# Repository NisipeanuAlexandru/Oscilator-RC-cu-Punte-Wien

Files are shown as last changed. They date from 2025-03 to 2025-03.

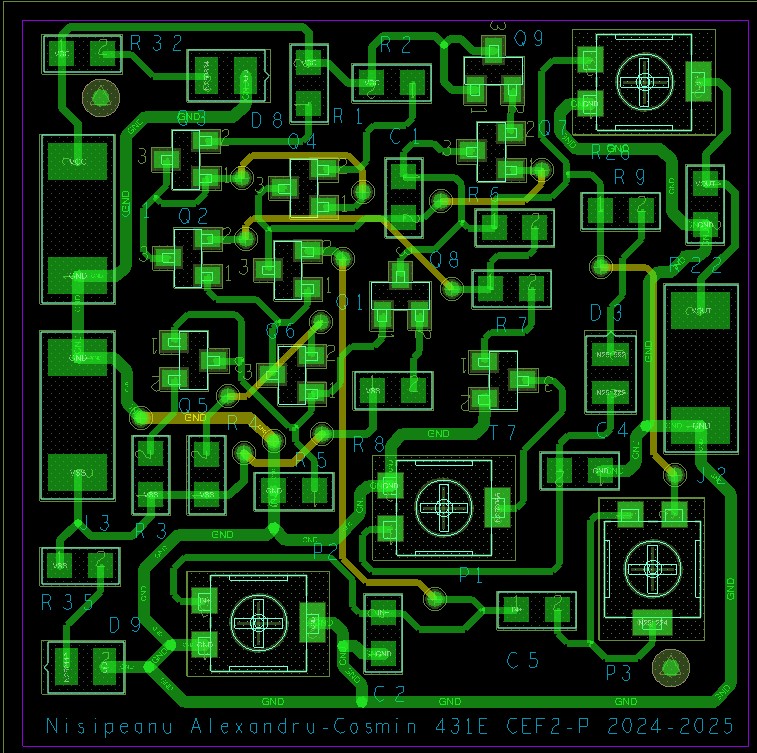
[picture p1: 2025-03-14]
Layout/layout.jpg

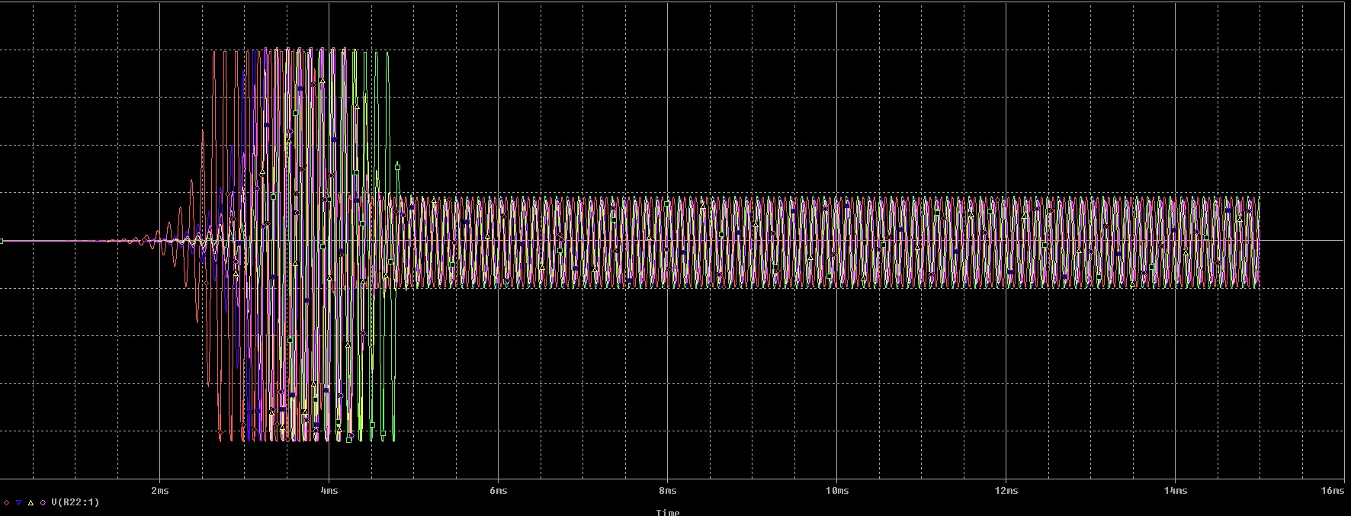
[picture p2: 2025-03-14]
Simulations/transient_-20_120.jpg

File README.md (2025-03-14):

# README - Oscilator RC cu Punte Wien

## Descriere Generală
Oscilatorul RC cu punte Wien este un circuit utilizat pentru generarea de semnale sinusoidale de frecvență reglabilă. Acesta este alcătuit dintr-o rețea RC în configurație Wien și un amplificator cu control automat al amplitudinii (TEC-J). Circuitul este destinat utilizării în diverse aplicații electronice unde este necesară o sursă de semnal sinusoidal stabilă și ajustabilă.

## Caracteristici Tehnice
- **Frecvență de oscilație reglabilă**: 7,5 - 45 kHz
- **Sarcină la ieșire**: 15 kΩ
- **Control automat al amplitudinii**: realizat cu TEC-J
- **Amplitudinea oscilației la ieșire**: 20/1,5*15 V
- **Domeniul temperaturilor de funcționare**: 0 - 70°C
- **Semnalizare a tensiunilor de alimentare**: LED

## Funcționalitate
Oscilatorul Wien utilizează o rețea de rezistențe și condensatori pentru a stabili frecvența de oscilație. Acesta include:
1. **Rețeaua Wien (RC)** - determină frecvența semnalului de ieșire.
2. **Amplificator operațional sau tranzistor** - menține oscilațiile în circuit.
3. **Control automat al amplitudinii** - stabilizează amplitudinea oscilatorului printr-un element de feedback, cum ar fi un TEC-J (Thermally Controlled Junction).
4. **Sistem de semnalizare LED** - indică prezența tensiunii de alimentare.

## Tehnologii de Realizare
Oscilatorul poate fi realizat utilizând două metode:
- **SMT & PCB**: Tehnologie avansată pentru performanță ridicată și fiabilitate (100 puncte max.)
  - Placă PCB FR4, dublu strat, dimensiuni 40x40mm
  - Componente SMD de tip 0805
  - Tranzistoare bipolare și TEC-MOS în capsule SMD (SOT23, D-PAK)
  - Layer special pentru marcaje și identificare
- **THT & Perfo-board**: Tehnologie mai simplă, accesibilă pentru prototipare rapidă (70 puncte max.)
  - Componente montate pe perfo-board
  - Necesită plan de plantare detaliat

## Simulare și Testare
- Se utilizează software-ul OrCAD pentru simulare și proiectare PCB.
- Se verifică funcționarea în intervalul de temperaturi specificat.
- Se validează fișierele Gerber și Excellon pentru fabricație PCB.

## Concluzie
Oscilatorul RC cu punte Wien este un circuit stabil și eficient pentru generarea semnalelor sinusoidale. Alegerea între SMT & PCB sau THT & Perfo-board depinde de cerințele aplicației și de nivelul de complexitate dorit în realizarea practică.

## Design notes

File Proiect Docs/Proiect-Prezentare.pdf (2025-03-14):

## UNIVERSITATEA NAȚIONALĂ DE ȘTIINȚĂ ȘI TEHNOLOGIE POLITEHNICA DIN BUCUREȘTI

Facultatea de Electronica, Telecomunicatii si Tehnologia Informatiei

Proiect CEF2 Tema:

## Oscilator RC cu reactive Wien

### Nisipeanu Alexandru-Cosmin

Grupa : 431E

Bucuresti 2024

Date initiale de proiectare: N=15
Să se proiecteze și realizeze un oscilator RC cu punte Wien având următoarele caracteristici:
- Frecventa de oscilaţie reglabilă în intervalul 7,5 45 [KHz];
- Sarcina la ieşire 15 [k ];
- Control automat al amplitudinii de oscilaţie realizat cu TEC-J;
- Amplitudinea oscilaţiei la ieşire 0,88 [V];
- Domeniul temperaturilor de funcționare: 0⁰

-70⁰C (verificabil prin testare în temperatură);

Semnalizarea prezenței tensiunilor de alimentare cu diodă de tip LED.

Schema bloc a circuitului

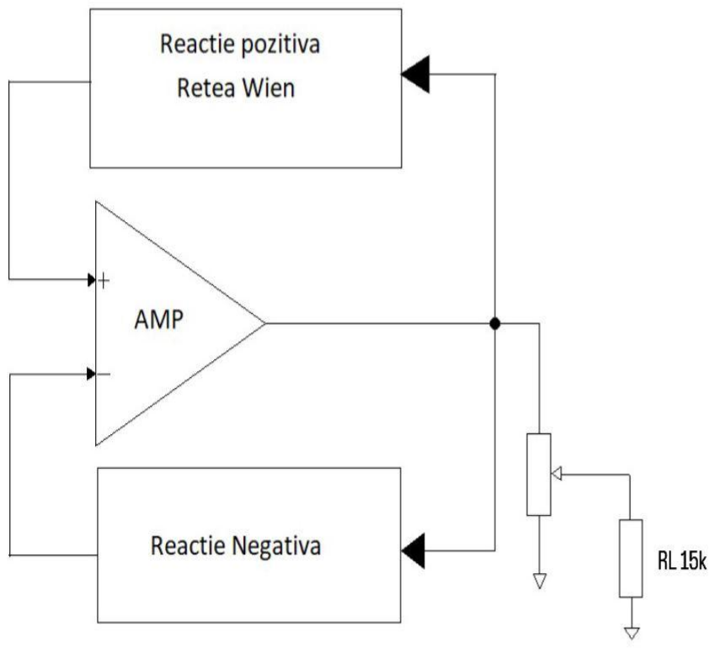
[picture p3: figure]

Oscilatorul RC:

Oscilatorul RC se utilizeaza in generatoare de audiofrecventa. Au reactive pozitiva selective, avand cuadripolul de reactive construit din rezistente si condensatoare.

Configuratia oscilatorului, in majoritatea situatiilor, corespunde unui amplificator cu reactive pozitiva cu transmisia pe bucla unitara egala cu A*β(ωn)=1.

Relația de mai sus reprezintă condiția de oscilație sau condiția Barkhausen, unde A este câștigul amplificatorului, iar β este funcția de transfer a rețelei de reacție pozitivă (RRP).

În general atât amplitudinea cât și factorul de transfer sunt mărimi complexe, astfel incât relaţia Barkhausen între numere complexe este echivalentă cu două condiţii reale:

Condiția de modul sau de amplitudine: | β (jω) | * | A (jω) | = 1;

Condiția de argument sau fază: arg(β) + arg(A) = φβ + φA = 0;

Schema electrica:

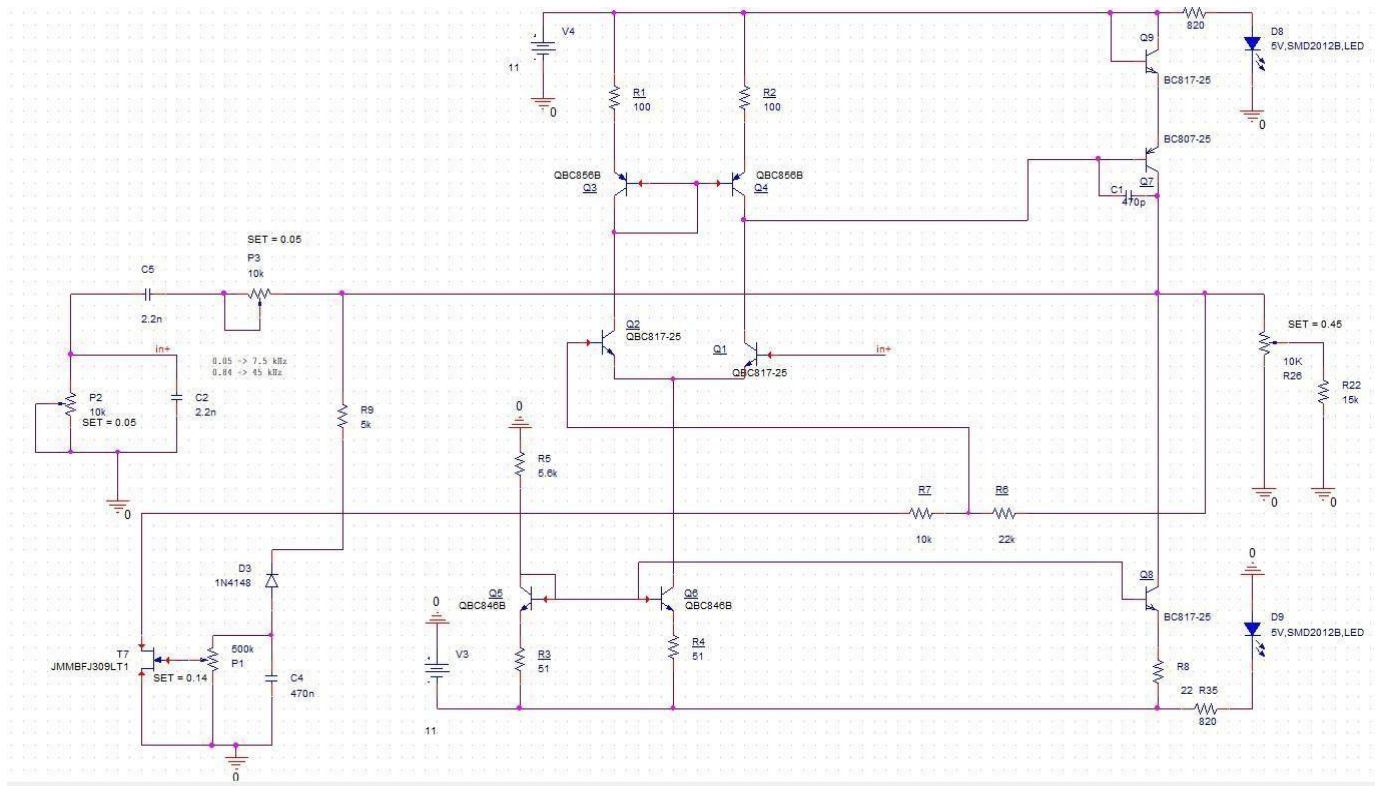
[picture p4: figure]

Etajul diferential de intrare este alcatuit din tranzistorii Q1 si Q2, acesta fiind un etaj de amplificare in tensiune si curent . Q3 si Q4 alcatuiesc sarcina activa a etajului diferential, egaland curentii prin cele doua ramuri ale acestuia. Q3 este referinta de oglinda /tranzistor dioda si perimte iesirea din etajul de amplificare asimetric, deci nu se injumatateste amplificarea etajului.

Q7 = al doilea etaj de amplificare de tip emitor comun in clasa A. Amplifica in tensiune, amplificarea sa in curent fiind ~ 1.

Etajele de amplificare pentru a functiona au nevoie de un curent constant.
Sursa de current Q6 polarizeaza etajul diferential.
Sursa de curent Q8 polarizeaza etajul de amplificare emitor comun (Q7) Curentul de referinta pentru polarizarea etajelor este generat pe ramura cu rezistorul R5 si R3 + tranzistorul in conexiune dioda Q5. Curentul generat astfel este preluat prin tranzistorul Q5 (referinta oglinzii) si distribuit la celelalte ramuri (catre etajul diferential – Q6, catre etajul emitor comun Q8)
Rezistoarele R3, R4, R8 permit obtinerea unor curenti diferiti prin fiecare ramura in functie de raportul rezistentelor acestora. De asemenea se numesc rezistente de degenerare care au rol in imperecherea tensiunilor VBE din oglinda de curent si de asemenea au rol in imbunatatirea variatiilor cu temperatura.

Reactia pozitiva:

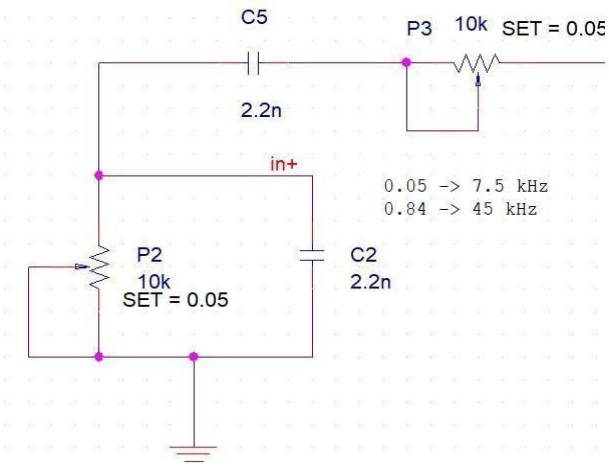
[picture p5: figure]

Componentele P3, P2, C5, C2 realizeaza un filtru trece banda care are frecventa de trecere egala cu frecventa de oscilatie.
Fosc = 1/2πRC, in conditia in care C = C5 = C2 si R = P3 = P2
Frecventa o reglam din potentiometrele de mai sus (P2,3)
C2=C5=2.2n;
P2=P3∈[0; 10]kOhm;

Reactia negative:

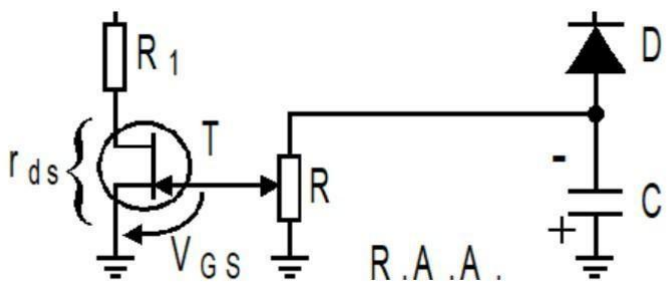
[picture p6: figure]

E constituita din rezistente R7, R6 si rezistenta canalului tranz JFET – T7. Se observă că acest circuit înlocuieşte una din rezistenţele circuitului de reacţie negativă al amplificatorului cu ajutorul căruia este realizat oscilatorul.
Dioda D realizează funcţia de detecţie (redresare de frecvenţă ridicată) a semnalului de la ieşirea oscilatorului lăsând să treacă doar alternanţa negativă, în care dioda este polarizată direct. Această tensiune pulsatorie încarcă condensatorul C la o tensiune negativă, condensatorul realizând filtrarea acestor pulsuri. Pentru ca tensiunea negativă de la bornele condensatorului să fie aproximativ constantă trebuie îndeplinită condiţia fosc RC >>1. Cu ajutorul potenţiometrului R este polarizat tranzistorul T care, fiind cu canal n, are o tensiune de comandă VGS < 0. Rezistenţa rds a tranzistorului T, ce face parte din reţeaua de reacţie negativă a amplificatorului, este dependentă de tensiunea de comandă
VGS. Cu cât valoarea absolută a tensiunii de comandă |VGS | este mai mare, cu atât canalul
conductor dintre drenă şi sursă este mai îngust şi deci rds este mai mare.
Această dependenţă a rezistenţei este însă comandată de amplitudinea tensiunii de oscilaţie prin intermediul circuitului descris anterior.
Deoarece expresia amplificării este AV=1+R6/R7>3 , variatia rezistentei rds determina:
-o scădere a amplificării dacă amplitudinea oscilaţiei are tendinţa de creştere; -o creştere a amplificării dacă amplitudinea oscilaţiei are tendinţa de scădere.

Calcule- punctul static de functionare

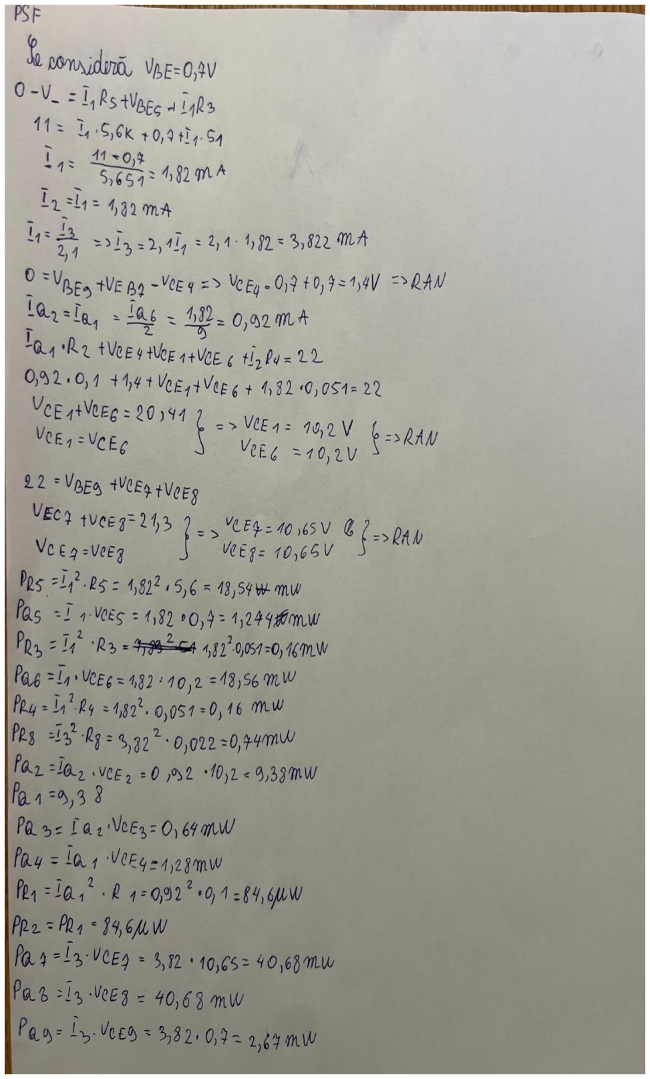
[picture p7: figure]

Punctul static de functionare- Simulat

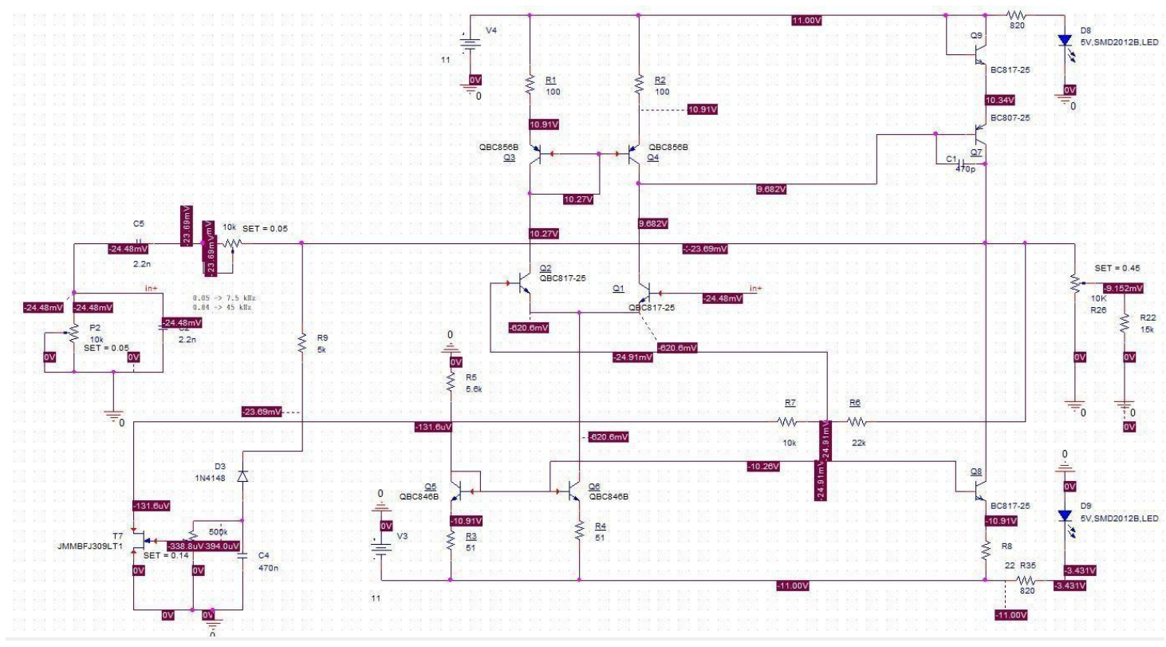
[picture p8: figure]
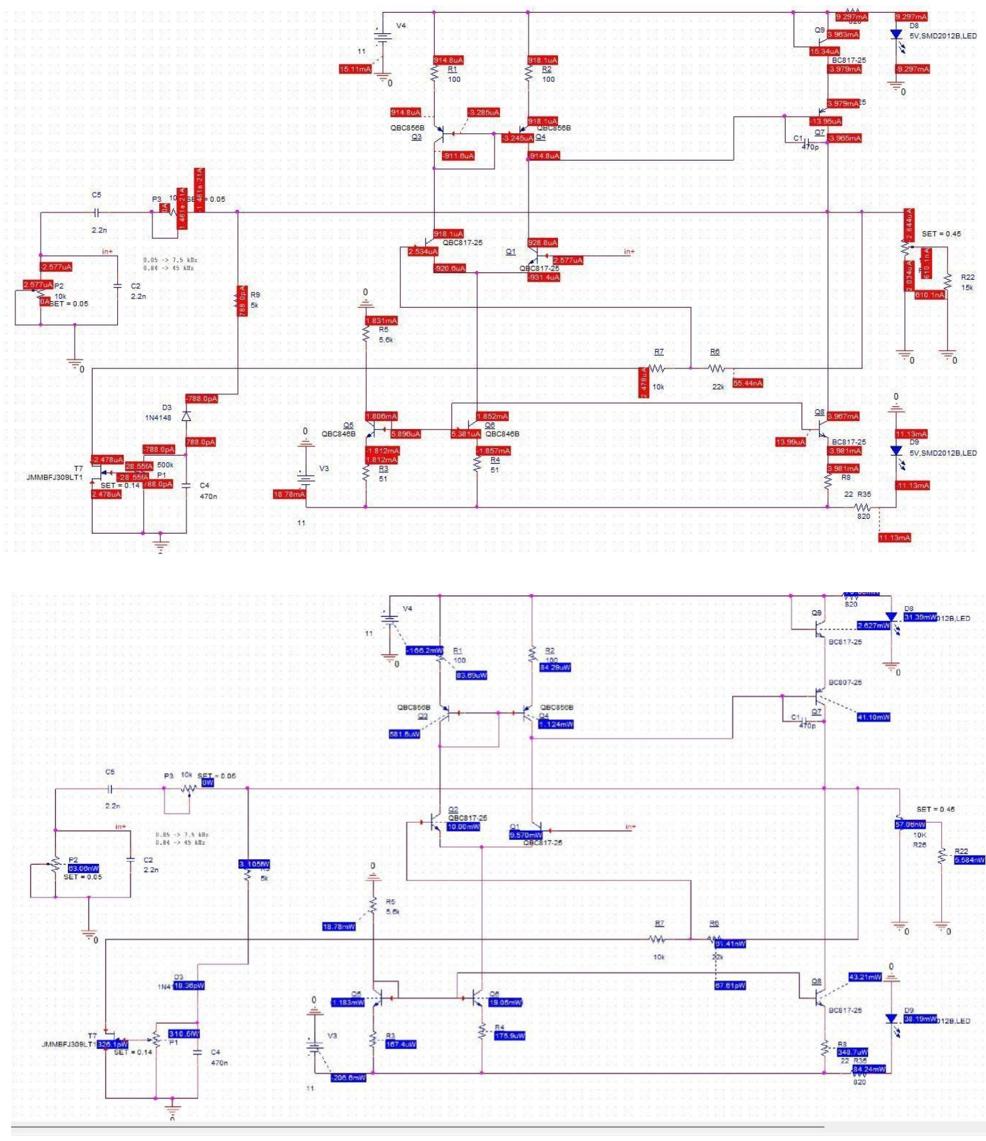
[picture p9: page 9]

Analiza in timp, transient

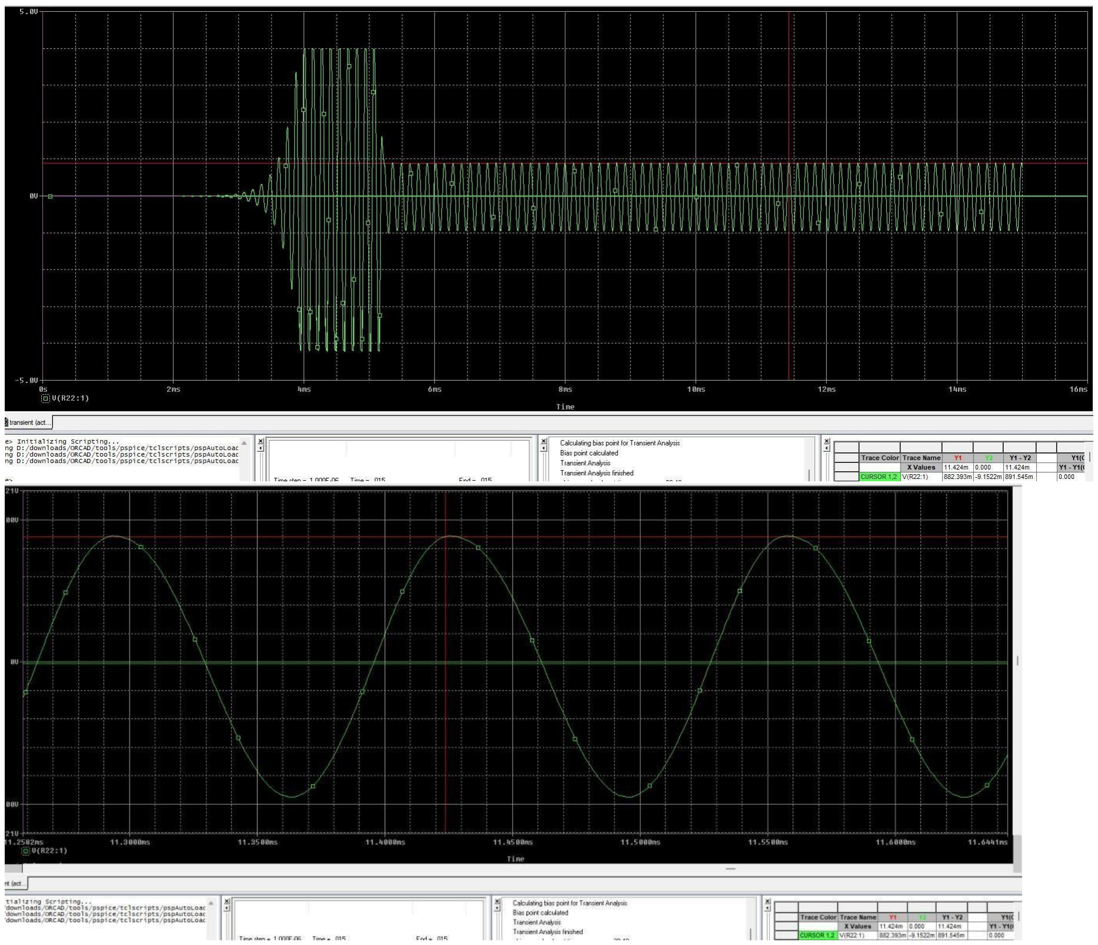
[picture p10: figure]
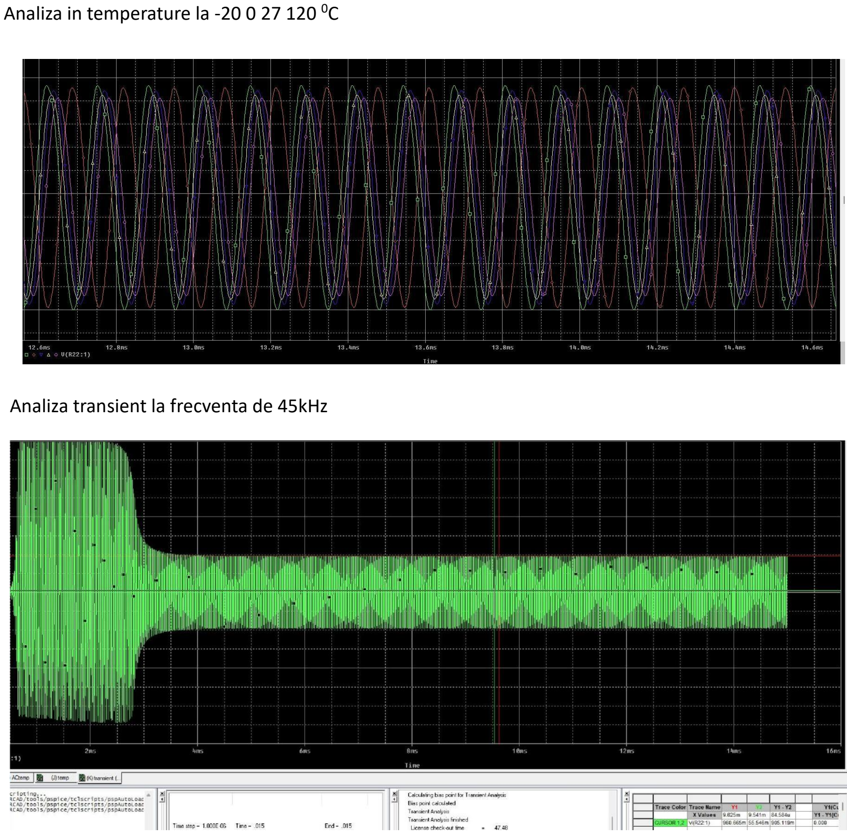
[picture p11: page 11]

Analiza in temperature la -20 0 27 120 ⁰C

Analiza transient la frecventa de 45kHz

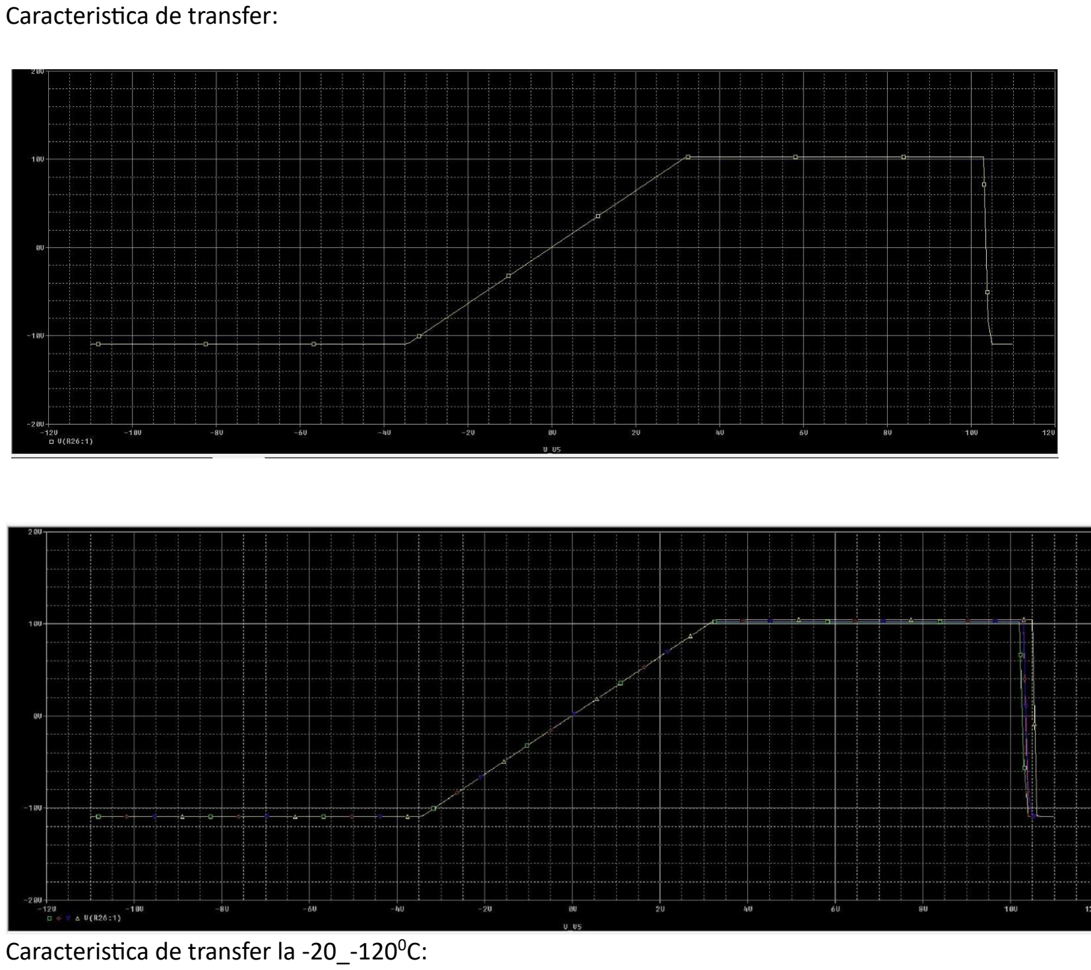
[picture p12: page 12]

Caracteristica de transfer:

Caracteristica de transfer la -20_-120⁰C:

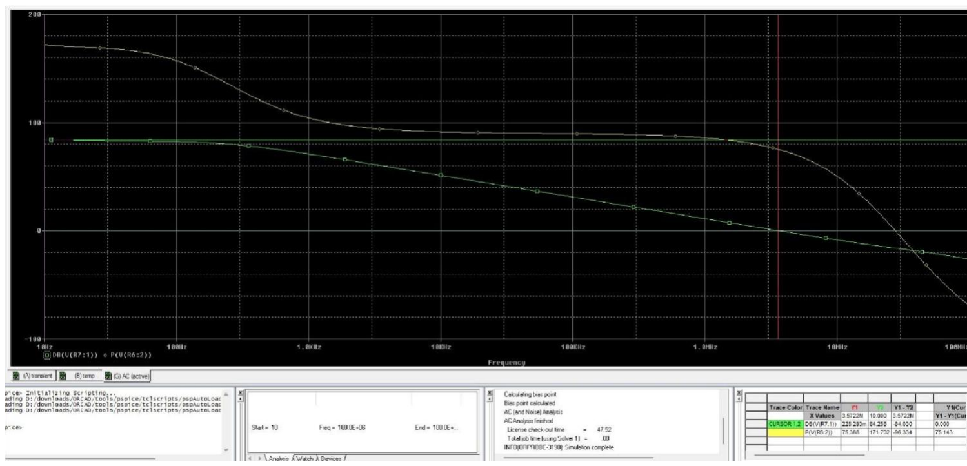
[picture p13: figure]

Analiza AC stabilitate:

Analiza AC staabilitate la -20_120⁰C:

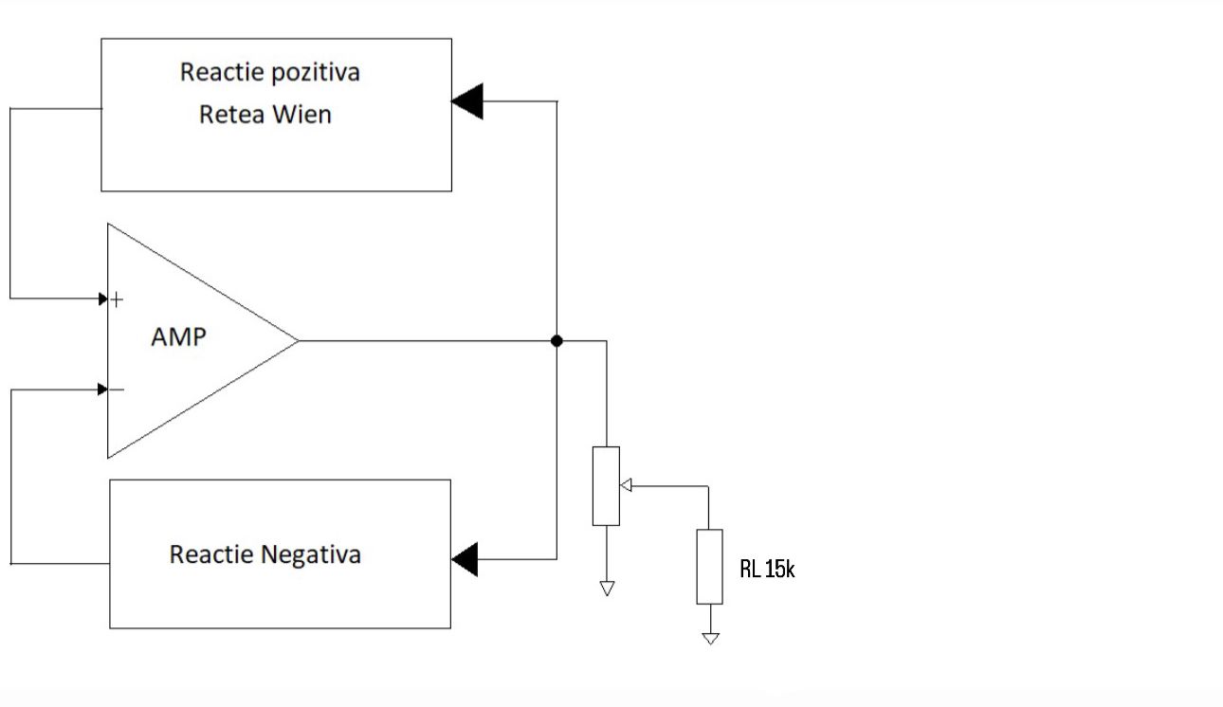
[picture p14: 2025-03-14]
Schema_bloc.jpg

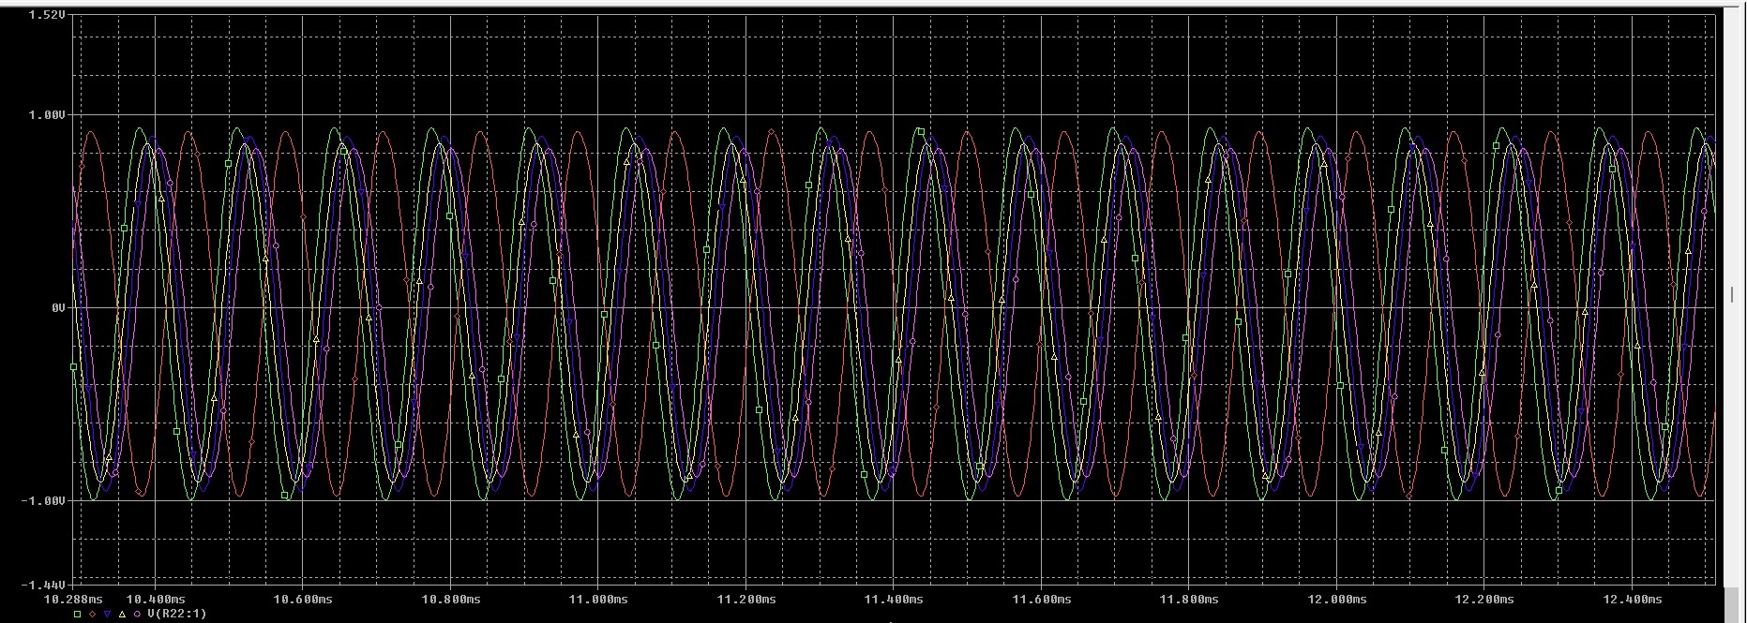
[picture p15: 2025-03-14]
Simulations/transient(zoom)_-20_120.jpg

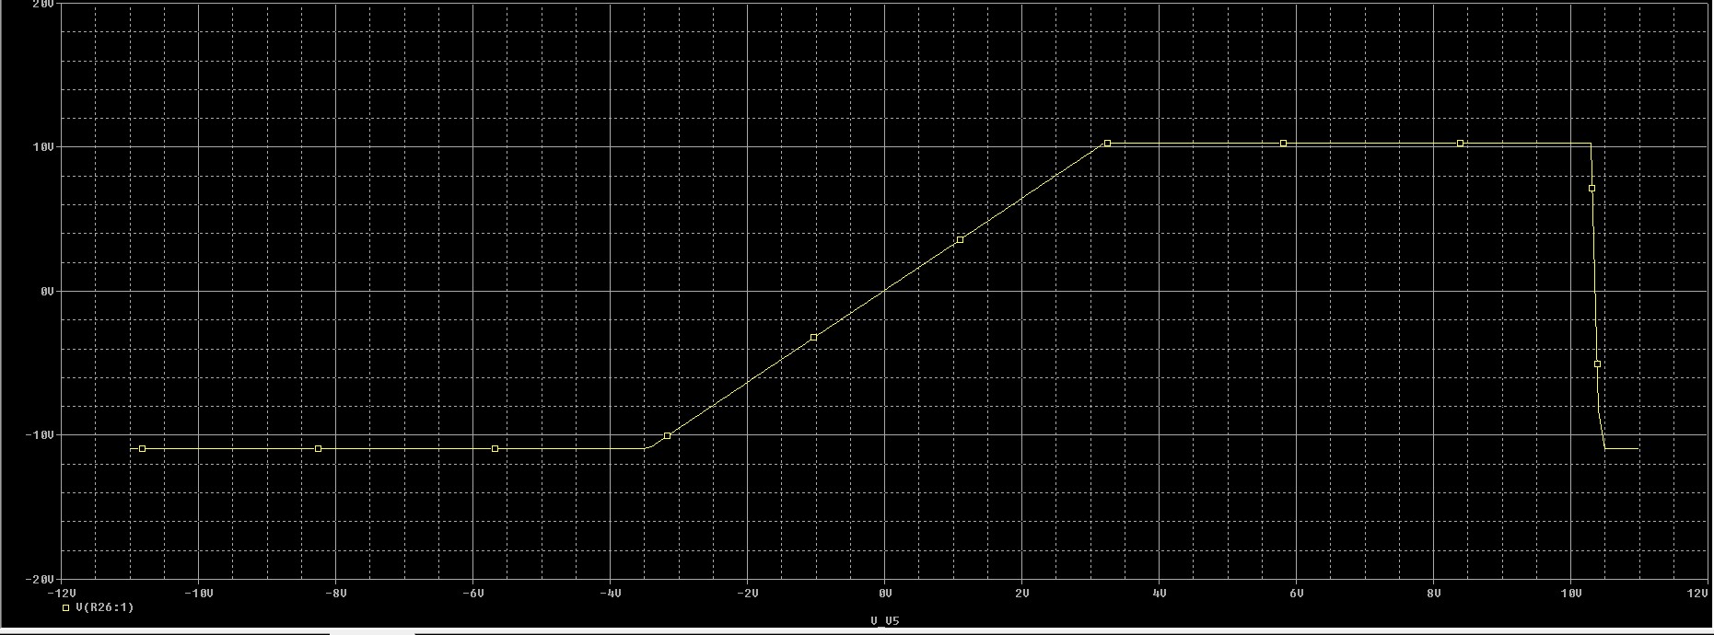
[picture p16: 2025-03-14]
Simulations/Caracteristica_de_transfer.jpg

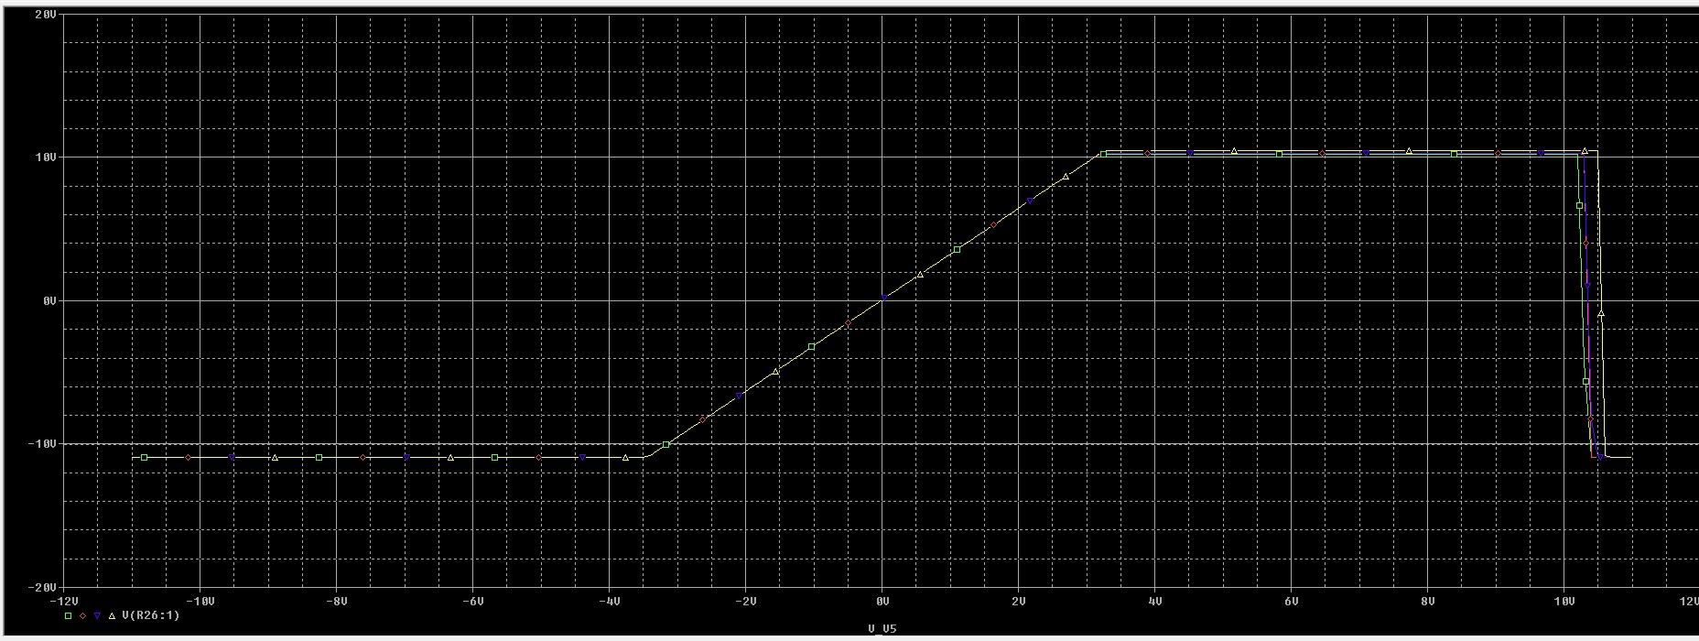
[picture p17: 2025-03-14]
Simulations/Caracteristica_de_transfer_-20_120.jpg

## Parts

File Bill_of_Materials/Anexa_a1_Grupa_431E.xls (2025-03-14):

Anexa a1 - Grupa 431E - Tema 1- Oscilator RC cu retea Wien
Nr. Crt. | Nume | Catalog | Cod distrib | Nume prod | Prod | Clasă | Qty fix | Qty final | Qty min | Descriere | Distribuitor | Pret (fara TVA) referinta/buc. TME România | Pret total pe reper (fara TVA) - propus
1 | 0 ohm | (LINK) (http://www.tme.eu/ro/details/smd1206-0r/rezistente-smd-1206/royal-ohm/1206s4j0000t5e/) | 1206S4J0000T5E | 1206S4J0000T5E | SR PASSIVES | rezistor | 0 |  | 0 | Rezistor: thick film; SMD; 1206; 0Ω; 0,25W; ±5%; -55÷125°C | TME România | 0.03841 | 0
2 | 0.47 | (LINK) (http://www.tme.eu/ro/details/smd0805-0r47/rezistente-smd-0805/royal-ohm/0805s8j047kt5e/) | SMD0805-0R47 | 0805S8J047KT5E | ROYAL OHM | rezistor | 20 |  | 0 | Rezistor SMD, chip, 0805, 0.47Ω, ±5%, 0.125W | TME România | 0.01454 | 0.2908
3 | 1 | (LINK) (https://www.tme.eu/ro/details/smd0805-1r/rezistente-smd-0805/royal-ohm/0805s8j010jt5e/) | SMD0805-1R-5% | 0805S8J010JT5E | ROYAL OHM | rezistor | 20 |  | 0 | Rezistor SMD, chip, 0805, 1Ω, ±5%, 0.125W | TME România | 0.01723 | 0.3446
4 | 4.7 | (LINK) (https://www.tme.eu/ro/details/smd0805-4r7/rezistente-smd-0805/royal-ohm/0805s8j047jt5e/) | SMD0805-4R7-5% | 0805S8J047JT5E | ROYAL OHM | rezistor | 10 |  | 0 | Rezistor SMD, chip, 0805, 4.7Ω, ±5%, 0.125W | TME România | 0.01723 | 0.1723
5 | 10 | (LINK) (https://www.tme.eu/ro/details/smd0805-10r/rezistente-smd-0805/royal-ohm/0805s8j0100t5e/) | SMD0805-10R-5% | 0805S8J0100T5E | ROYAL OHM | rezistor | 10 |  | 0 | Rezistor SMD, chip, 0805, 10Ω, ±5%, 0.125W | TME România | 0.01723 | 0.1723
6 | 22 | (LINK) (https://www.tme.eu/ro/details/smd0805-22r-1%25/rezistente-smd-0805/royal-ohm/0805s8f220jt5e/) | SMD0805-22R-1% | 0805S8F220JT5E | ROYAL OHM | rezistor | 20 |  | 1 | Rezistor SMD, chip, 0805, 22Ω, ±1%, 0.125W | TME România | 0.02127 | 0.4254
7 | 33 | (LINK) (https://www.tme.eu/ro/details/smd0805-33r/rezistente-smd-0805/royal-ohm/0805s8j0330t5e/) | SMD0805-33R-5% | 0805S8J0330T5E | ROYAL OHM | rezistor | 20 |  | 0 | Rezistor SMD, chip, 0805, 33Ω, ±5%, 0.125W | TME România | 0.01723 | 0.3446
8 | 51 | (LINK) (http://www.tme.eu/ro/details/rc0805jr-0751r/rezistente-smd-0805/yageo/rc0805jr-0751rl/) | SMD0805-51R-5% | 0805S8J0510T5E | ROYAL OHM | rezistor | 40 |  | 2 | Rezistor SMD, chip, 0805, 51Ω, ±5%, 0.125W | TME România | 0.0261 | 1.044
9 | 68 | (LINK) (http://www.tme.eu/ro/details/smd0805-68r-1%25/rezistente-smd-0805/royal-ohm/0805s8f680jt5e/) | SMD0805-68R-1% | 0805S8F680JT5E | ROYAL OHM | rezistor | 10 |  | 0 | Rezistor SMD, chip, 0805, 68Ω, ±1%, 0.125W | TME România | 0.04662 | 0.4662
10 | 82 | (LINK) (https://www.tme.eu/ro/details/wf08p-82r-5%25/rezistente-smd-0805/walsin/wf08p820jtl/) | SMD0805-82R-5% | WF08P820JTL | WALSIN | rezistor | 20 |  | 0 | Rezistor SMD, chip, 0805, 82Ω, ±5%, 0.125W | TME România | 0.0172 | 0.344
11 | 100 | (LINK) (https://www.tme.eu/ro/details/smd0805-100r/rezistente-smd-0805/royal-ohm/0805s8j0101t5e/) | SMD0805-100R-5% | 0805S8J0101T5E | ROYAL OHM | rezistor | 60 |  | 2 | Rezistor SMD, chip, 0805, 100Ω, ±5%, 0.125W | TME România | 0.01723 | 1.0338
12 | 150 | (LINK) (https://www.tme.eu/ro/details/smd0805-150r/rezistente-smd-0805/royal-ohm/0805s8j0151t5e/) | SMD0805-150R-5% | 0805S8F1500T5E | ROYAL OHM | rezistor | 30 |  | 0 | Rezistor SMD, chip, 0805, 150Ω, ±5%, 0.125W | TME România | 0.01723 | 0.5169
13 | 220 | (LINK) (http://www.tme.eu/ro/details/smd0805-220r-1%25/rezistente-smd-0805/royal-ohm/0805s8f2200t5e/) | SMD0805-220R-5% | 0805S8J0221T5E | ROYAL OHM | rezistor | 30 |  | 0 | Rezistor SMD, chip, 0805, 220Ω, ±5%, 0.125W | TME România | 0.02127 | 0.6381
14 | 330 | (LINK) (https://www.tme.eu/ro/details/smd0805-330r/rezistente-smd-0805/royal-ohm/0805s8j0331t5e/) | SMD0805-330R-5% | 0805S8J0331T5E | ROYAL OHM | rezistor | 30 |  | 0 | Rezistor SMD, chip, 0805, 330Ω, ±5%, 0.125W | TME România | 0.01723 | 0.5169
15 | 470 | (LINK) (https://www.tme.eu/ro/details/smd0805-470r/rezistente-smd-0805/royal-ohm/0805s8j0471t5e/) | SMD0805-470R-5% | 0805S8J0471T5E | ROYAL OHM | rezistor | 30 |  | 0 | Rezistor SMD, chip, 0805, 470Ω, ±5%, 0.125W | TME România | 0.01723 | 0.5169
16 | 510 | (LINK) (https://www.tme.eu/ro/details/smd0805-510r/rezistente-smd-0805/royal-ohm/0805s8j0511t5e/) | SMD0805-510R-5% | 0805S8J0511T5E | YAGEO | rezistor | 30 |  | 0 | Rezistor SMD, chip, 0805, 510Ω, ±5%, 0.125W | TME România | 0.01723 | 0.5169
17 | 680 | (LINK) (https://www.tme.eu/ro/details/smd0805-680r/rezistente-smd-0805/royal-ohm/0805s8j0681t5e/) | SMD0805-680R-5% | 0805S8J0681T5E | ROYAL OHM | rezistor | 30 |  | 0 | Rezistor SMD, chip, 0805, 680Ω, ±5%, 0.125W | TME România | 0.01723 | 0.5169
18 | 820 | (LINK) (https://www.tme.eu/ro/details/smd0805-820r/rezistente-smd-0805/royal-ohm/0805s8j0821t5e/) | SMD0805-820R-5% | 0805S8J0821T5E | ROYAL OHM | rezistor | 30 |  | 2 | Rezistor SMD, chip, 0805, 820Ω, ±5%, 0.125W | TME România | 0.01723 | 0.5169
19 | 910 | (LINK) (https://www.tme.eu/ro/details/rc0805jr-07910r/rezistente-smd-0805/yageo/rc0805jr-07910rl/) | SMD0805-910R-5% | RC0805JR-07910RL | YAGEO | rezistor | 40 |  | 0 | Rezistor SMD, chip, 0805, 910Ω, ±5%, 0.125W | TME România | 0.0261 | 1.044
20 | 1k | (LINK) (https://www.tme.eu/ro/details/smd0805-1k/rezistente-smd-0805/royal-ohm/0805s8j0102t5e/) | SMD0805-1K-5% | 0805S8J0102T5E | ROYAL OHM | rezistor | 100 |  | 0 | Rezistor SMD, chip, 0805, 1kΩ, ±5%, 0.125W | TME România | 0.01723 | 1.723
21 | 1.5k | (LINK) (https://www.tme.eu/ro/details/wf08p-1k5-5%25/rezistente-smd-0805/walsin/wf08p152jtl/) | SMD0805-1K5-5% | WF08P152JTL | WALSIN | rezistor | 40 |  | 0 | Rezistor SMD, chip, 0805, 1.5kΩ, ±5%, 0.125W | TME România | 0.0172 | 0.688
22 | 1.8k | (LINK) (https://www.tme.eu/ro/details/smd0805-1k8/rezistente-smd-0805/royal-ohm/0805s8j0182t5e/) | SMD0805-1K8-5% | 0805S8J0182T5E | ROYAL OHM | rezistor | 30 |  | 0 | Rezistor SMD, chip, 0805, 1.8kΩ, ±5%, 0.125W | TME România | 0.01723 | 0.5169
23 | 2k | (LINK) (https://www.tme.eu/ro/details/smd0805-2k/rezistente-smd-0805/royal-ohm/0805s8j0202t5e/) | SMD0805-2K-5% | 0805S8J0202T5E | ROYAL OHM | rezistor | 80 |  | 0 | Rezistor SMD, chip, 0805, 2kΩ, ±5%, 0.125W | TME România | 0.01723 | 1.3784
24 | 2.2k | (LINK) (https://www.tme.eu/ro/details/smd0805-2k2/rezistente-smd-0805/royal-ohm/0805s8j0222t5e/) | SMD0805-2K2-5% | 0805S8J0222T5E | ROYAL OHM | rezistor | 30 |  | 0 | Rezistor SMD, chip, 0805, 2.2kΩ, ±5%, 0.125W | TME România | 0.01723 | 0.5169
25 | 2.7k | (LINK) (https://www.tme.eu/ro/details/smd0805-2k7/rezistente-smd-0805/royal-ohm/0805s8j0272t5e/) | SMD0805-2K7-5% | 0805S8F2701T5E | ROYAL OHM | rezistor | 30 |  | 0 | Rezistor SMD, chip, 0805, 2.7kΩ, ±5%, 0.125W | TME România | 0.01723 | 0.5169
26 | 3.3k | (LINK) (https://www.tme.eu/ro/details/smd0805-3k3/rezistente-smd-0805/royal-ohm/0805s8j0332t5e/) | SMD0805-3K3-5% | 0805S8J0332T5E | ROYAL OHM | rezistor | 30 |  | 0 | Rezistor SMD, chip, 0805, 3.3kΩ, ±5%, 0.125W | TME România | 0.01723 | 0.5169
27 | 3.9k | (LINK) (https://www.tme.eu/ro/details/smd0805-3k9/rezistente-smd-0805/royal-ohm/0805s8j0392t5e/) | SMD0805-3K9-5% | 0805S8J0392T5E | ROYAL OHM | rezistor | 20 |  | 0 | Rezistor SMD, chip, 0805, 3.9kΩ, ±5%, 0.125W | TME România | 0.01723 | 0.3446
28 | 4.7k | (LINK) (https://www.tme.eu/ro/details/smd0805-4k7/rezistente-smd-0805/royal-ohm/0805s8j0472t5e/) | SMD0805-4K7-5% | 0805S8J0472T5E | ROYAL OHM | rezistor | 30 |  | 0 | Rezistor SMD, chip, 0805, 4.7kΩ, ±5%, 0.125W | TME România | 0.01723 | 0.5169
29 | 5.6k | (LINK) (https://www.tme.eu/ro/details/smd0805-5k6/rezistente-smd-0805/royal-ohm/0805s8j0562t5e/) | SMD0805-5K6-5% | 0805S8J0562T5E | ROYAL OHM | rezistor | 60 |  | 2 | Rezistor SMD, chip, 0805, 5.6kΩ, ±5%, 0.125W | TME România | 0.01723 | 1.0338
30 | 6.8k | (LINK) (https://www.tme.eu/ro/details/rc0805jr-076k8/rezistente-smd-0805/yageo/rc0805jr-076k8l/) | SMD0805-6K8-5% | RC0805JR-076K8L | YAGEO | rezistor | 20 |  | 0 | Rezistor SMD, chip, 0805, 6.8kΩ, ±5%, 0.125W | TME România | 0.0261 | 0.522
31 | 8.2k | (LINK) (https://www.tme.eu/ro/details/smd0805-8k2/rezistente-smd-0805/royal-ohm/0805s8j0822t5e/) | SMD0805-8K2-5% | 0805S8J0822T5E | ROYAL OHM | rezistor | 30 |  | 0 | Rezistor SMD, chip, 0805, 8.2kΩ, ±5%, 0.125W | TME România | 0.01723 | 0.5169
32 | 9.1k | (LINK) (https://www.tme.eu/ro/details/smd0805-9k1/rezistente-smd-0805/royal-ohm/0805s8j0912t5e/) | SMD0805-9K1-5% | 0805S8J0912T5E | ROYAL OHM | rezistor | 20 |  | 0 | Rezistor SMD, chip, 0805, 9.1kΩ, ±5%, 0.125W | TME România | 0.01723 | 0.3446
33 | 10k | (LINK) (https://www.tme.eu/ro/details/smd0805-10k/rezistente-smd-0805/royal-ohm/0805s8j0103t5e/) | SMD0805-10K-5% | 0805S8J0103T5E | ROYAL OHM | rezistor | 100 |  | 1 | Rezistor SMD, chip, 0805, 10kΩ, ±5%, 0.125W | TME România | 0.01723 | 1.723
34 | 15k | (LINK) (https://www.tme.eu/ro/details/smd0805-15k/rezistente-smd-0805/royal-ohm/0805s8j0153t5e/) | SMD0805-15K-5% | 0805S8J0153T5E | ROYAL OHM | rezistor | 30 |  | 1 | Rezistor SMD, chip, 0805, 15kΩ, ±5%, 0.125W | TME România | 0.01723 | 0.5169
35 | 22k | (LINK) (https://www.tme.eu/ro/details/smd0805-22k/rezistente-smd-0805/royal-ohm/0805s8j0223t5e/) | SMD0805-22K-5% | 0805S8J0223T5E | ROYAL OHM | rezistor | 30 |  | 1 | Rezistor SMD, chip, 0805, 22kΩ, ±5%, 0.125W | TME România | 0.01723 | 0.5169
36 | 47k | (LINK) (http://www.tme.eu/ro/details/smd0805-47k/rezistente-smd-0805/royal-ohm/0805s8j0473t5e/) | SMD0805-47K-5% | 0805S8J0473T5E | ROYAL OHM | rezistor | 40 |  | 0 | Rezistor: thick film; SMD; 0805; 47kΩ; 0,125W; ±5%; -55÷125°C | TME România | 0.01723 | 0.6892
37 | 68k | (LINK) (https://www.tme.eu/ro/details/smd0805-68k/rezistente-smd-0805/royal-ohm/0805s8j0683t5e/) | SMD0805-68K-5% | 0805S8J0683T5E | ROYAL OHM | rezistor | 20 |  | 0 | Rezistor SMD, chip, 0805, 68kΩ, ±5%, 0.125W | TME România | 0.01723 | 0.3446
38 | 100k | (LINK) (https://www.tme.eu/ro/details/smd0805-100k/rezistente-smd-0805/royal-ohm/0805s8j0104t5e/) | SMD0805-100K-5% | 0805S8J0104T5E | ROYAL OHM | rezistor | 100 |  | 0 | Rezistor SMD, chip, 0805, 100kΩ, ±5%, 0.125W | TME România | 0.01723 | 1.723
39 | 150k | (LINK) (http://www.tme.eu/ro/details/smd0805-150k/rezistente-smd-0805/royal-ohm/0805s8j0154t5e/) | SMD0805-150K-5% | 0805S8J0154T5E | ROYAL OHM | rezistor | 30 |  | 0 | Rezistor SMD, chip, 0805, 150kΩ, ±5%, 0.125W | TME România | 0.01723 | 0.5169
40 | 180k | (LINK) (http://www.tme.eu/ro/details/smd0805-180k/rezistente-smd-0805/royal-ohm/0805s8j0184t5e/) | SMD0805-180K-5% | 0805S8J0184T5E | ROYAL OHM | rezistor | 30 |  | 0 | Rezistor SMD, chip, 0805, 180kΩ, ±5%, 0.125W | TME România | 0.01723 | 0.5169
41 | 220k | (LINK) (https://www.tme.eu/ro/details/smd0805-220k/rezistente-smd-0805/royal-ohm/0805s8j0224t5e/) | SMD0805-220K-5% | 0805S8J0224T5E | ROYAL OHM | rezistor | 30 |  | 0 | Rezistor SMD, chip, 0805, 220kΩ, ±5%, 0.125W | TME România | 0.01723 | 0.5169
42 | 330k | (LINK) (https://www.tme.eu/ro/details/smd0805-330k/rezistente-smd-0805/royal-ohm/0805s8j0334t5e/) | SMD0805-330K-5% | 0805S8J0334T5E | ROYAL OHM | rezistor | 30 |  | 0 | Rezistor SMD, chip, 0805, 330kΩ, ±5%, 0.125W | TME România | 0.01723 | 0.5169
43 | 390k | (LINK) (https://www.tme.eu/ro/details/smd0805-390k/rezistente-smd-0805/royal-ohm/0805s8j0394t5e/) | SMD0805-390K-5% | 0805S8J0394T5E | ROYAL OHM | rezistor | 30 |  | 0 | Rezistor SMD, chip, 0805, 390kΩ, ±5%, 0.125W | TME România | 0.01723 | 0.5169
44 | 510k | (LINK) (https://www.tme.eu/ro/details/smd0805-510k/rezistente-smd-0805/royal-ohm/0805s8j0514t5e/) | SMD0805-510K-5% | 0805S8J0514T5E | ROYAL OHM | rezistor | 30 |  | 0 | Rezistor SMD, chip, 0805, 510kΩ, ±5%, 0.125W | TME România | 0.01723 | 0.5169
45 | 1M | (LINK) (https://www.tme.eu/ro/details/crcw08051m00jntabc/rezistente-smd-0805/vishay/) | SMD0805-1M-5% | CRCW08051M00JNTABC | VISHAY | rezistor | 30 |  | 0 | Rezistor SMD, chip, 0805, 1MΩ, ±5%, 0.125W | TME România | 0.01151 | 0.3453
46 | 2M | (LINK) (http://www.tme.eu/ro/details/smd0805-2m/rezistente-smd-0805/royal-ohm/0805waj-2m-t5e/) | SMD0805-2M7 5% | 0805WAJ 2M T5E | ROYAL OHM | rezistor | 30 |  | 0 | Rezistor SMD, chip, 0805, 2MΩ, ±1%, 0.125W | TME România | 0.01723 | 0.5169
47 | 5,1M | (LINK) (http://www.tme.eu/ro/details/smd0805-5m1/rezistente-smd-0805/royal-ohm/0805s8j0515t5e/) | SMD0805-5M1 5% | RC0805FR-075M1 | Yageo | rezistor | 30 |  | 0 | Rezistor SMD, chip, 0805, 5.1MΩ, ±1%, 0.125W | TME România | 0.01723 | 0.5169
48 | 10M | (LINK) (https://www.tme.eu/ro/details/0805s8j0106t5e/rezistente-smd-0805/royal-ohm/) | SMD0805-10M 5% | 0805S8J0106T5E | ROYAL OHM | rezistor | 40 |  | 0 | Rezistor SMD, chip, 0805, 10MΩ, ±5%, 0.125W | TME România | 0.01723 | 0.6892
49 | 100ohm | (LINK) (https://www.tme.eu/ro/details/ts53yl100r/trimere-smd-cu-o-singura-tura/vishay/ts53yl101mr10/) | 1804GSMD-100R | 1804GSMD-100R | SR PASSIVES | potențiometru | 15 |  | 0 | Potențiome-tru liniar, simplă tură, SMD, 100Ω, ±10%, 100ppm/°C, 0.25W | TME România | 3.77 | 56.55
50 | 500ohm | (LINK) (https://www.tme.eu/ro/details/ts53yl500r/trimere-smd-cu-o-singura-tura/vishay/ts53yl501mr10/) | 1804GSMD-500R | 1804GSMD-500R | VISHAY | potențiometru | 0 |  | 0 | Potențiome-tru liniar, simplă tură, SMD, 500Ω, ±10%, 100ppm/°C, 0.25W | TME România | 2.19 | 0
51 | 2k | (LINK) (https://www.tme.eu/ro/details/ts53yl2k/trimere-smd-cu-o-singura-tura/vishay/ts53yl202mr10/) | TS53YL202MR10 | TS53YL202MR10 | VISHAY | potențiometru | 0 |  | 0 | Potențiome-tru liniar, simplă tură, SMD, 2kΩ, ±20%, 100ppm/°C, 0.25W | TME România | 2.84 | 0
52 | 5k | (LINK) (http://www.tme.eu/ro/details/3314g-1-502e/trimere-smd-cu-o-singura-tura/bourns/) | 3314G-1-502E | 3314G-1-502E | BOURNS | potențiometru | 0 |  | 0 | Potențiome-tru liniar, simplă tură, SMD, 5kΩ, ±20%, 100ppm/°C, 0.25W | TME România | 3.45 | 0
53 | 10k | (LINK) (http://www.tme.eu/ro/details/3314g-1-103e/trimere-smd-cu-o-singura-tura/bourns/) | 3314G-1-103E | 3314G-1-103E | BOURNS | potențiometru | 30 |  | 3 | Potențiome-tru liniar, simplă tură, SMD, 10kΩ, ±20%, 100ppm/°C, 0.25W | TME România | 3.0573 | 91.719
54 | 50k | (LINK) (http://www.tme.eu/ro/details/3314g-1-503e/trimere-smd-cu-o-singura-tura/bourns/) | 3314G-1-503E | 3314G-1-503E | BOURNS | potențiometru | 0 |  | 0 | Potențiome-tru liniar, simplă tură, SMD, 50kΩ, ±20%, 100ppm/°C, 0.25W | TME România | 2.84 | 0
55 | 100k | (LINK) (http://www.tme.eu/ro/details/ts53yl100k/trimere-smd-cu-o-singura-tura/vishay/ts53yl104mr10/) | TS53YL104MR10 | TS53YL104MR10 | VISHAY | potențiometru | 32 |  | 0 | Potențiome-tru liniar, simplă tură, SMD, 100kΩ, ±20%, 100ppm/°C, 0.25W | TME România | 2.61 | 83.52
56 | 500k | (LINK) (http://www.tme.eu/ro/details/3314g-1-504e/trimere-smd-cu-o-singura-tura/bourns/) | 3314G-1-504E | 3314G-1-504E | BOURNS | potențiometru | 10 |  | 1 | Potențiome-tru liniar, simplă tură, SMD, 500kΩ, ±10%, 100ppm/°C, 0.25W | TME România | 2.8802 | 28.802
 | TOTAL - Componente pasive (rezistoare de valori fixe şi reglabile) |  |  |  |  |  |  |  |  | FARA TVA = | 289.8316 | CU TVA= | 359.391184
57 | 4.7pF | (LINK) (http://www.tme.eu/ro/details/cc0805crnpo94r7/condensatoare-mlcc-smd-0805/yageo/cc0805crnpo9bn4r7/) | CC0805CRNPO9BN4R7 | CC0805CRNPO9BN4R7 | YAGEO | condensator | 20 |  | 0 | ceramic; MLCC; 4,7pF; 50V; C0G; ±0,25pF; SMD; 0805 | TME România | 0.16643 | 3.3286
58 | 10pF | (LINK) (http://www.tme.eu/ro/details/cc0805jrnpo9100/condensatoare-mlcc-smd-0805/yageo/cc0805jrnpo9bn100/) | CC0805JRNPO9BN100 | CC0805JRNPO9BN100 | YAGEO | condensator | 20 |  | 0 | ceramic; MLCC; 10pF; 50V; C0G; ±5%; SMD; 0805 | TME România | 0.1649 | 3.298
59 | 47pF | (LINK) (http://www.tme.eu/ro/details/cl21c470jbannnc/condensatoare-mlcc-smd-0805/samsung/) | CL21C470JBANNNC | CL21C470JBANNNC | SAMSUNG | condensator | 20 |  | 0 | Condensator: ceramic; MLCC; 47pF; 50V; C0G; ±5%; SMD; 0805; -55÷125°C | TME România | 0.11097 | 2.2194
60 | 100pF | (LINK) (http://www.tme.eu/ro/details/cl21c101jbannnc/condensatoare-mlcc-smd-0805/samsung/) | CL21C101JBANNNC | CL21C101JBANNNC | SAMSUNG | condensator | 20 |  | 0 | Condensator: ceramic; MLCC; 100pF; 50V; C0G; ±5%; SMD; 0805 | TME România | 0.05427 | 1.0854
61 | 470pF | (LINK) (https://www.tme.eu/ro/details/cl21c471jbannnc/condensatoare-mlcc-smd-0805/samsung/) | CL21C471JBANNNC | CL21C471JBANNNC | SAMSUNG | condensator | 20 |  | 1 | Condensator: ceramic; MLCC; 470pF; 50V; X7R; ±10%; SMD; 0805 | TME România | 0.12123 | 2.4246
62 | 1nF | (LINK) (https://www.tme.eu/ro/details/cc0805jrnpo9102/condensatoare-mlcc-smd/yageo/cc0805jrnpo9bn102/) | CL21C102JBCNNNC | CL21C102JBCNNNC | SAMSUNG | condensator | 40 |  | 0 | Condensator MLCC; 1nF; 50V; C0G (NP0); ±5%; SMD; 0805 | TME România | 0.06487 | 2.5948
63 | 2.2nF | (LINK) (https://www.tme.eu/ro/details/cl21b222jbannnc/condensatoare-mlcc-smd-0805/samsung/) | CC0805JRNPO9BN102 | CC0805JRNPO9BN102 | YAGEO | condensator | 40 |  | 2 | Condensator: ceramic; MLCC; 2,2nF; 50V; X7R; ±10%; SMD; 0805 | TME România | 0.1485 | 5.94
64 | 4.7nF | (LINK) (https://www.tme.eu/ro/details/cl21b472kbannnc/condensatoare-mlcc-smd-0805/samsung/) | CL21B472KBANNNC | CL21B472KBANNNC | SAMSUNG | condensator | 40 |  | 0 | Condensator MLCC, SMD, 0805, 4.7nF, ±5%, 50V, X7R | TME România | 0.08943 | 3.5772
65 | 5.6nF | (LINK) (https://www.tme.eu/ro/details/cl21b562kbannnc/condensatoare-mlcc-smd-0805/samsung/) | CL21B562KBANNNC | CL21B562KBANNNC | SAMSUNG | condensator | 40 |  | 0 | Condensator MLCC, SMD, 0805, 5.6nF, ±5%, 50V, X7R | TME România | 0.04517 | 1.8068
66 | 10nF | (LINK) (https://www.tme.eu/ro/details/cl21b103kbannnd/condensatoare-mlcc-smd-0805/samsung/) | CL21B103KBANNND | CL21B103KBANNND | SAMSUNG | condensator | 40 |  | 0 | Condensator MLCC, SMD, 0805, 10nF, ±5%, 50V, X7R | TME România | 0.06093 | 2.4372
67 | 22nF | (LINK) (http://www.tme.eu/ro/details/cl21b223kcfnnne/condensatoare-mlcc-smd-0805/samsung/) | CL21B223KBANNNC | CL21B223KBANNNC | SAMSUNG | condensator | 40 |  | 0 | Condensator: ceramic; MLCC; 22nF; 100V; X7R; ±10%; SMD; 0805 | TME România | 0.13823 | 5.5292
68 | 33nF | (LINK) (https://www.tme.eu/ro/details/vj0805y333kxacw1bc/condensatoare-mlcc-smd-0805/vishay/) | VJ0805Y333KXACW1BC | VJ0805Y333KXACW1BC | VISHAY | condensator | 40 |  | 0 | Condensator: ceramic; MLCC; 33nF; 50V; X7R; ±10%; SMD; 0805 | TME România | 0.05417 | 2.1668
69 | 100nF | (LINK) (https://www.tme.eu/ro/details/cl21b104kbcnnnc/condensatoare-mlcc-smd/samsung/) | CL21B104KBCNNNC | CL21B104KBCNNNC | SAMSUNG | condensator | 40 |  | 0 | ceramic; MLCC; 100nF; 50V; X7R; ±10%; SMD; 0805 | TME România | 0.3759 | 15.036
70 | 220nF | (LINK) (http://www.tme.eu/ro/details/cl21b224kafnnne/condensatoare-mlcc-smd-0805/samsung/) | CL21B224KAFNNNE | CL21B224KAFNNNE | SAMSUNG | condensator | 40 |  | 0 | Condensator: ceramic; MLCC; 220nF; 25V; X7R; ±10%; SMD; 0805 | TME România | 0.10247 | 4.0988
71 | 330nF | (LINK) (https://www.tme.eu/ro/details/grm219r71h334ka88d/condensatoare-mlcc-smd-0805/murata/) | GRM219R71H334KA88D | GRM219R71H334KA88D | MURATA | condensator | 30 |  | 0 | Condensator: ceramic; MLCC; 330nF; 50V; X7R; ±10%; SMD; 0805 | TME România | 0.5972 | 17.916
72 | 470nF | (LINK) (https://www.tme.eu/ro/details/cc0805mry5v8474/condensatoare-mlcc-smd-0805/yageo/cc0805mry5v8bb474/) | CC0805MRY5V8474 | CC0805MRY5V8BB474 | YAGEO | condensator | 30 |  | 1 | Condensator: ceramic; MLCC; 470nF; 50V; Y5V; -20÷+80%; SMD; 0805 | TME România | 0.0758 | 2.274
73 | 1uF | (LINK) (https://www.tme.eu/ro/details/cl21b105kbfnnng/condensatoare-mlcc-smd-0805/samsung/) | CL21B105KBFNNNG | CL21B105KBFNNNG | SAMSUNG | condensator | 20 |  | 0 | Condensator: ceramic; MLCC; 1uF; 50V; X7R; ±20%; SMD; 0805 | TME România | 0.25253 | 5.0506
74 | 2.2uF | (LINK) (https://www.tme.eu/ro/details/grm21br61h225ka73l/condensatoare-mlcc-smd-0805/murata/) | GRM21BR61H225KA73L | GRM21BR61H225KA73L | MURATA | condensator | 20 |  | 0 | Condensator: ceramic; MLCC; 2,2uF; 25V; X5R; ±10%; SMD; 0805 | TME România | 0.4486 | 8.972
75 | 4.7uF | (LINK) (https://www.tme.eu/ro/details/cl21a475kaqnnng/condensatoare-mlcc-smd-0805/samsung/) | CL21A475KAQNNNG | CL21A475KAQNNNG | SAMSUNG | condensator | 20 |  | 0 | ceramic; MLCC; 4,7uF; 25V; X5R; ±10%; SMD; 0805 | TME România | 0.25373 | 5.0746
76 | 10uF | (LINK) (https://www.tme.eu/ro/details/eee1ha100sp/condensatoare-electrolitice-smd/panasonic/) | EEE1HA100SP | EEE1HA100SP | PANASONIC | condensator | 16 |  | 0 | Condensator: electrolitic; SMD; 10uF; 50V | TME România | 0.2284 | 3.6544
 | TOTAL - Componente pasive (condensatoare) |  |  |  |  |  |  |  |  | FARA TVA = | 98.4844 | CU TVA= | 122.120656
77 | 4148 | (LINK) (http://www.tme.eu/ro/details/1n4148-0805/diode-universale-smd/dc-components/cd4148ws0805c/) | 1N4148-0805 | CD4148WS(0805C) | DC Components | diodă pn | 50 |  | 1 | Diodă comutație, SMD, 0805, 300mA, 100V | TME România | 0.04555 | 2.2775
78 | LED | (LINK) (https://www.tme.eu/ro/details/of-smd2012b/diode-led-smd-colorate/optoflash/) | OF-SMD2012B | OF-SMD2012B | OPTOFLASH | LED | 15 |  | 2 | LED albastru, SMD, 0805, 150-200mcd, 476nm, 120° | TME România | 0.1264 | 1.896
79 | 2.7V | (LINK) (https://www.tme.eu/ro/details/bzx84-c2v7.215/diode-zener-smd/nexperia/bzx84-c2v7-215/) | BZX84C2V7 | BZX84-C2V7LT1G | ON Semiconductor | diodă Zener | 0 |  | 0 | Diodă Zener, SMD, SOT23, 2,7V, ±5%, 0.25W | TME România | 0.05732 | 0
80 | 5.1V | (LINK) (https://www.tme.eu/ro/details/bzx84-c5v1.215/diode-zener-smd/nexperia/) | BZX84C5V1 | BZX84-C5V1 | NEXPERIA | diodă Zener | 10 |  | 0 | Diodă Zener, SMD, SOT23, 5,1V, ±5%, 0.3W | TME România | 0.06245 | 0.6245
81 | 5.6V | (LINK) (https://www.tme.eu/ro/details/bzx84b5v6-dio/diode-zener-smd/diotec-semiconductor/bzx84b5v6/) | BZX84B5V6 | BZX84B5V6 | DIOTEC SEMICONDUCTOR | diodă Zener | 10 |  | 0 | Diodă Zener, SMD, SOT23, 5,6V, ±5%, 0.3W | TME România | 0.0839 | 0.839
82 | 6.2V | (LINK) (https://www.tme.eu/ro/details/bzx84-c6v2.215/diode-zener-smd/nexperia/) | BZX84C6V2 | BZX84-C6V2 | NEXPERIA | diodă Zener | 0 |  | 0 | Diodă Zener, SMD, SOT23, 6.2V, ±5%, 0.3W | TME România | 0.06618 | 0
83 | 6.8V | (LINK) (https://www.tme.eu/ro/details/bzx84-c6v8.215/diode-zener-smd/nexperia/) | BZX84C6V8 | BZX84-C6V8 | NEXPERIA | diodă Zener | 0 |  | 0 | Diodă Zener, SMD, SOT23, 6.8V, ±5%, 0.3W | TME România | 0.05686 | 0
84 | 8.2V | (LINK) (https://www.tme.eu/ro/details/bzx84-c8v2.215/diode-zener-smd/nexperia/) | BZX84C8V2 | BZX84-C8V2 | NEXPERIA | diodă Zener | 0 |  | 0 | Diodă Zener, SMD, SOT23, 8.2V, ±5%, 0.3W | TME România | 0.05686 | 0
85 | 10V | (LINK) (https://www.tme.eu/ro/details/bzx84-c10.215/diode-zener-smd/nexperia/) | BZX84C10 | BZX84-C10 | NEXPERIA | diodă Zener | 0 |  | 0 | Diodă Zener, SMD, SOT23, 10V, ±5%, 0.3W | TME România | 0.05686 | 0
86 | PNP | (LINK) (http://www.tme.eu/ro/details/bc856b-dio/tranzistori-smd-pnp/diotec-semiconductor/bc856b/) | BC856B | BC856B | DIOTEC | tranzistor bipolar | 100 |  | 2 | Tranzistor bipolar PNP, SMD, SOT23, 80V, 100mA | TME România | 0.04055 | 4.055
87 | NPN | (LINK) (https://www.tme.eu/ro/details/bc846b-dio/tranzistori-smd-npn/diotec-semiconductor/bc846b/) | BC846B | BC846B | DIOTEC | tranzistor bipolar | 100 |  | 2 | Tranzistor bipolar NPN, SMD, SOT23, 65V, 100mA | TME România | 0.03379 | 3.379
89 | N-JFET | (LINK) (http://www.tme.eu/ro/details/mmbfj309lt1g/tranzistori-canal-n-smd/on-semiconductor/) | MMBFJ309LT1G | MMBFJ309LT1G | ON Semiconductor | tranzistor NJFET | 50 |  | 1 | Tranzistor N-JFET, SMD, SOT23, 25V, 30mA | TME România | 0.8063 | 40.315
90 | P-JFET | (LINK) (http://www.tme.eu/ro/details/mmbfj177lt1g/tranzistori-canal-p-smd/on-semiconductor/) | MMBFJ177LT1G | MMBFJ177LT1G | ON Semiconductor | tranzistor PJFET | 10 |  | 0 | Tranzistor P-JFET, SMD, SOT23, 30V, 20mA | TME România | 0.8808 | 8.808
91 | NPN | (LINK) (http://www.tme.eu/ro/details/bc817-25-dio/tranzistori-smd-npn/diotec-semiconductor/bc817-25/) | BC817-25-DIO | BC817-25-DIO | NXP | tranzistor bipolar | 10 |  | 4 | Tranzistor bipolar NPN, SMD, SOT23, 45V, 800mA | TME România | 0.0494 | 0.494
93 | PNP | (LINK) (http://www.tme.eu/ro/details/bc807-25-dio/tranzistori-smd-pnp/diotec-semiconductor/bc807-25/) | BC807-25-DIO | BC807-25-DIO | NXP | tranzistor bipolar | 20 |  | 1 | Tranzistor bipolar PNP, SMD, SOT23, 45V, 800mA | TME România | 0.05406 | 1.0812
94 | NPN | (LINK) (http://www.tme.eu/ro/details/mjd31cg/tranzistori-smd-npn/on-semiconductor/) | MJD31CG | MJD31CG | ON Semiconductor | tranzistor bipolar | 0 |  | 0 | Tranzistor bipolar NPN, SMD, DPACK, 100V, 3A, 15W | TME România | 0.7037 | 0
96 | PNP | (LINK) (http://www.tme.eu/ro/details/mjd32cg/tranzistori-smd-pnp/on-semiconductor/) | MJD32CG | MJD32CG | ON Semiconductor | tranzistor bipolar | 0 |  | 0 | Tranzistor bipolar PNP, SMD, DPACK, 100V, 3A, 15W | TME România | 0.783 | 0
97 | Nmos | (LINK) (http://www.tme.eu/ro/details/irfr120npbf/tranzistori-canal-n-smd/international-rectifier/) | IRFR120NPBF | IRFR120NPBF | International Rectifier | tranzistor NMOS | 0 |  | 0 | Tranzistor N-MOSFET, SMD, DPAK, 100V, 9.1A, 20V, 39W | TME România | 1.03 | 0
 | TOTAL - Componente semiconductoare (tranzistoare bipolare şi cu efect de câmp, diode, LED, etc.) |  |  |  |  |  |  |  |  | FARA TVA = | 91.0692 | CU TVA= | 112.925808
98 | Conn2p | (LINK) (http://www.tme.eu/ro/details/zl301-40p/pini-cu-benzi-si-soclu/ninigi/) | ZL301-40P | ZL301-40P | NINIGI | Sir pini, pas 2,54mm, SMD | 0 |  | 3 | Sir pini, pas 2,54mm, SMD, tip tata, bareta de 40 pini | TME România | 2.3027 | 0
99 | FUSE | (LINK) (http://www.tme.eu/ro/details/3413.0116.11/sigurante-smd-1206-ultrarapide/schurter/) | 3413.0116.11 | 3413.0116.11 | SCHURTER | sigu-ranță | 0 |  | 0 | Siguranță sticlă, SMD, 1206, 1.25A, 48mΩ | TME România | 0 | 0
 | Total - Conectică, sigurante fuzibile, etc. |  |  |  |  |  |  |  |  | FARA TVA = | 0 | CU TVA= | 0
 | Total general |  |  |  |  |  |  |  |  | FARA TVA = | 479.3852 | CU TVA= | 570.468388

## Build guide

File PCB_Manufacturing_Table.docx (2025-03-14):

General info document for PCB manufacturing
No. | Item Name | File Name | | | | | | Info / Remarks / Notes
| BOARD
1 | Board Name / Number | Nisipeanu Alexandru-Cosmin,431E, CEF2-P 2024-2025 | | | | | | -
2 | Revision Date | 15 Decembrie 2024 | | | | | | -
3 | Board Size | 40 x 40 mm² | | | | | | -
4 | Board Quantity | 1 | | | | | | -
5 | Material / Dielectric Type | FR4 | | | | | | -
6 | Board Thickness | 1.6 mm | | | | | | -
7 | Copper Thickness | 18 μm | | | | | | -
| LAYERS
8 | Number of Electrical Layers | 2 | | | | | | -
9 | Copper Layer TOP | TOP.art | | | | | | -
10 | Copper Layer BOTTOM | BOTTOM.art | | | | | | -
11 | Copper GND Plane | - | | | | | | -
12 | Copper PWR Plane | - | | | | | | -
13 | Copper INNER 1 | - | | | | | | -
14 | Copper INNER 2 | - | | | | | | -
15 | Solder Mask TOP | SMTOP.art | | | | | | -
16 | Solder Mask BOTTOM | SMBOT.art | | | | | | -
17 | Solder Paste TOP | SPTOP.art | | | | | | -
18 | Solder Paste BOTTOM | - | | | | | | -
19 | Peelable Mask TOP | - | | | | | | -
20 | Peelable Mask BOTTOM | - | | | | | | -
21 | Silk Screen TOP | SSTOP.art | | | | | | -
22 | Silk Screen BOTTOM | - | | | | | | -
23 | Board Outline | BO.art | | | | | | -
24 | Fabrication Drawing | FAB.art | | | | | | -
| MILLING & DRILLING
25 | Mill Drawing | - | | | | | | -
26 | Drill Drawing | DRILL.drl | | | | | | -
27 | N.C. Drill (for both PH & NPH) | - | | | | | | -
28 | N.C. Drill / Plated Holes (PH) | - | | | | | | -
29 | N.C. Drill / Non-Plated Holes (PH) | - | | | | | | -
| FINISHING
30 | Panelisation | - | | | | | | -
31 | Electrical Test | - | | | | | | -
32 | Copper Finishing | x | HASL | | OSP | | | ENIG
33 | Board Outline Machining | | Routing | | Milling | | x | V-Cutting
34 | Final remarks | - | | | | -
